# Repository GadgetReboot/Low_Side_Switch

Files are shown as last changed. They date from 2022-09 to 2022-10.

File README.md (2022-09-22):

# Low Side Switch
16 channel low-side switch for driving resistive/inductive loads<br><br>
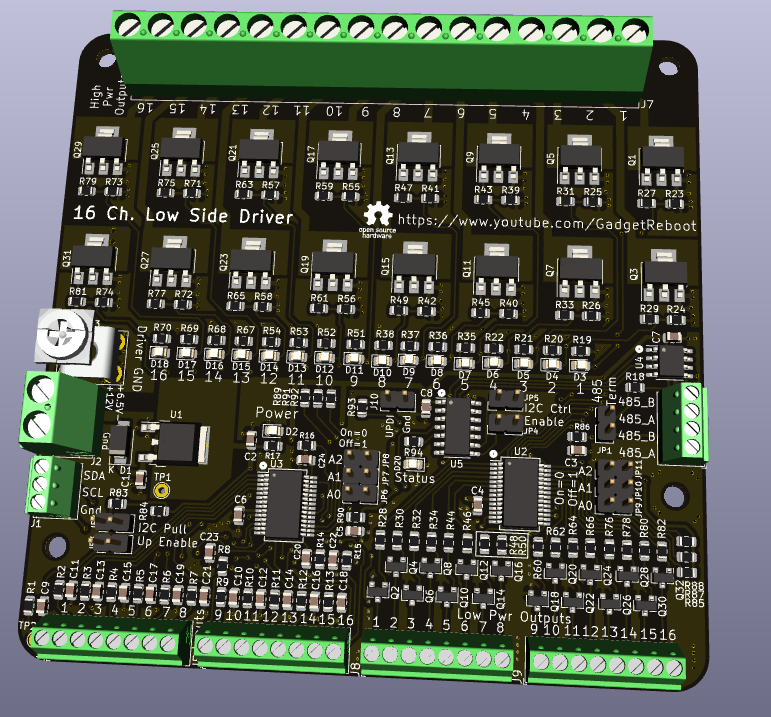
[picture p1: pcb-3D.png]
pcb
<br><br>
[PCBs are available at PCBWay.com][pcbway] <br><br>
This project is intended for use in a hobby electronics project environment, eg. a controlled research and development work shop to assist in the design and test of various other projects, ideas, and concepts.

It is not intended to be used as a stand alone or complete/refined product.

This design may be refined on an ongoing basis as needed, including design corrections or changes to fit or function.

If used in a situation where safety or other regulatory approval is required, it is the responsibility of the user of this design to ensure all applicable laws and regulations are followed.<br><br>

Shield: [][cc-by-sa]

This work is licensed under a
[Creative Commons Attribution-ShareAlike 4.0 International License][cc-by-sa].

[][cc-by-sa]

[cc-by-sa]: http://creativecommons.org/licenses/by-sa/4.0/
[cc-by-sa-image]: https://licensebuttons.net/l/by-sa/4.0/88x31.png
[cc-by-sa-shield]: https://img.shields.io/badge/License-CC%20BY--SA%204.0-lightgrey.svg
[pcbway]: https://www.pcbway.com/project/shareproject/16_Channel_Low_Side_Switch_Driver_fce9e224.html

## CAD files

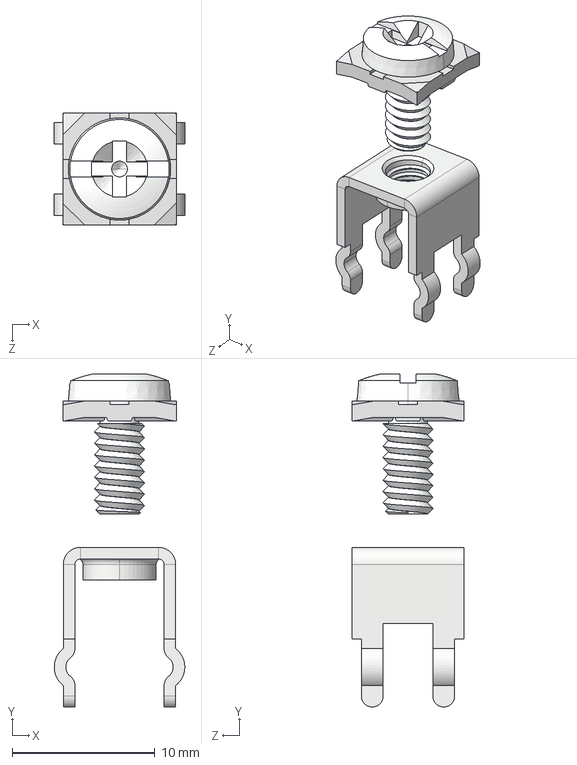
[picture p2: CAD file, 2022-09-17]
KiCad/3D_Models/keystone-PN7691-SEMS.STEP
9.14 x 23.3 x 7.87 mm

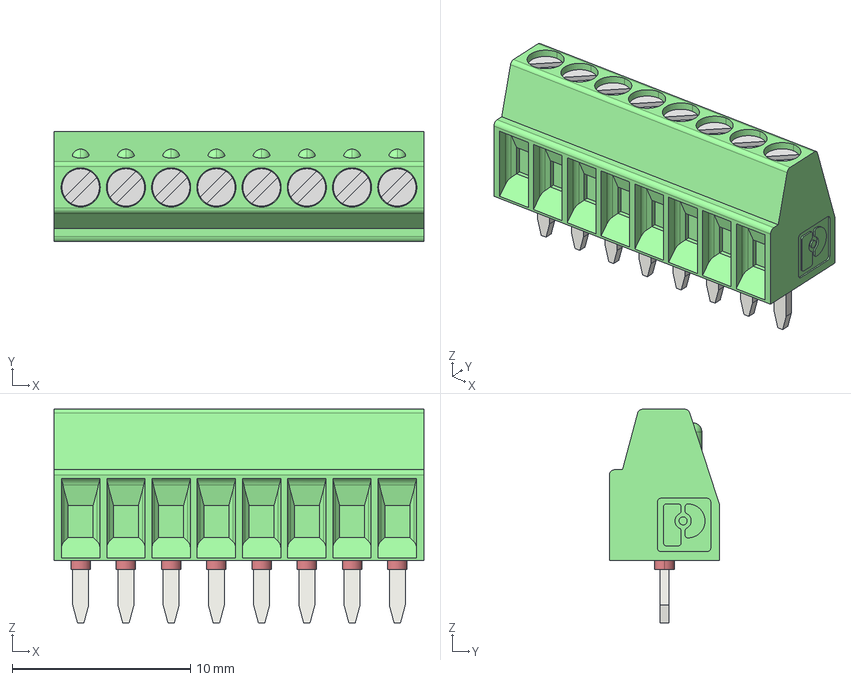
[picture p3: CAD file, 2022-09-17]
KiCad/3D_Models/1725711.stp
20.8 x 6.20 x 12.0 mm
bohrloch.2 x 8
MPT_0_5-8-2_54

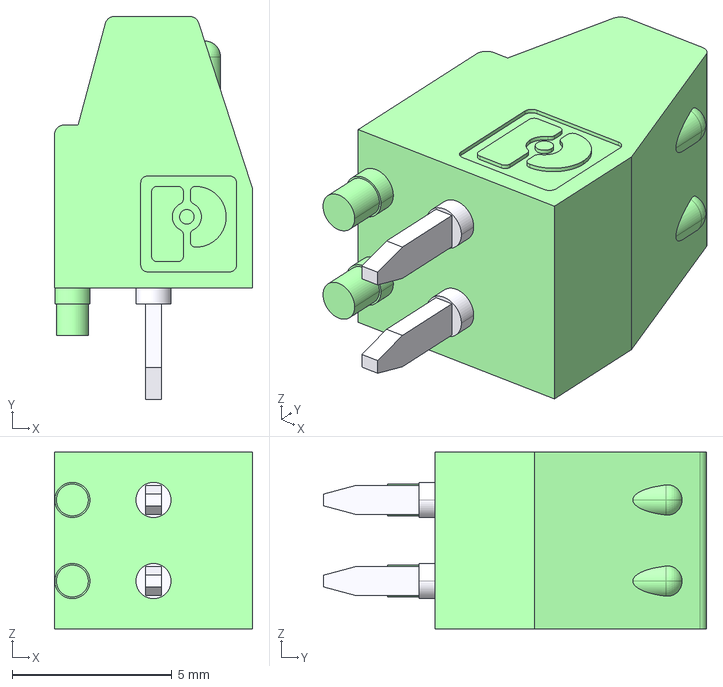
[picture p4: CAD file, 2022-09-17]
KiCad/3D_Models/1725656.stp
6.20 x 12.0 x 5.54 mm

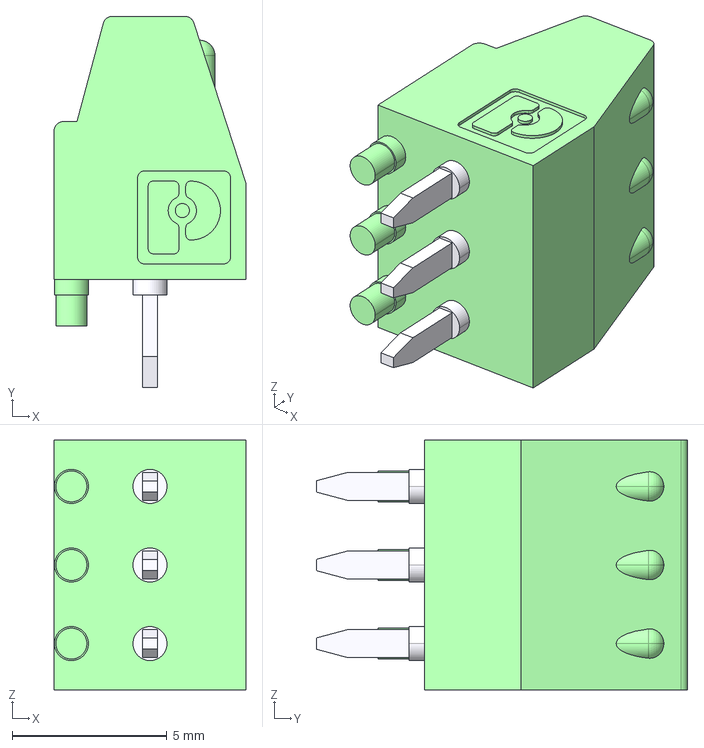
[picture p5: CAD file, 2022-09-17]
KiCad/3D_Models/1725669.stp
6.20 x 12.0 x 8.08 mm

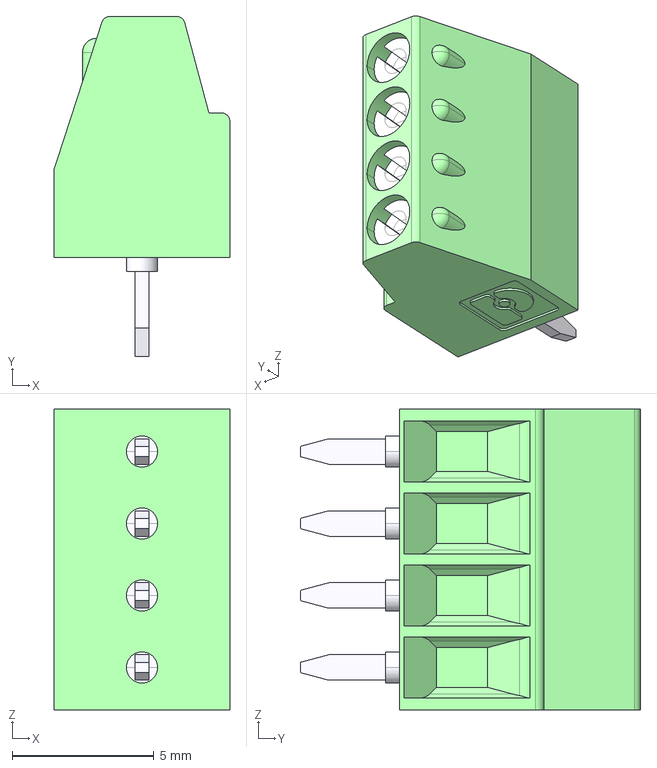
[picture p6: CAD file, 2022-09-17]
KiCad/3D_Models/1725672.stp
6.20 x 12.0 x 10.6 mm

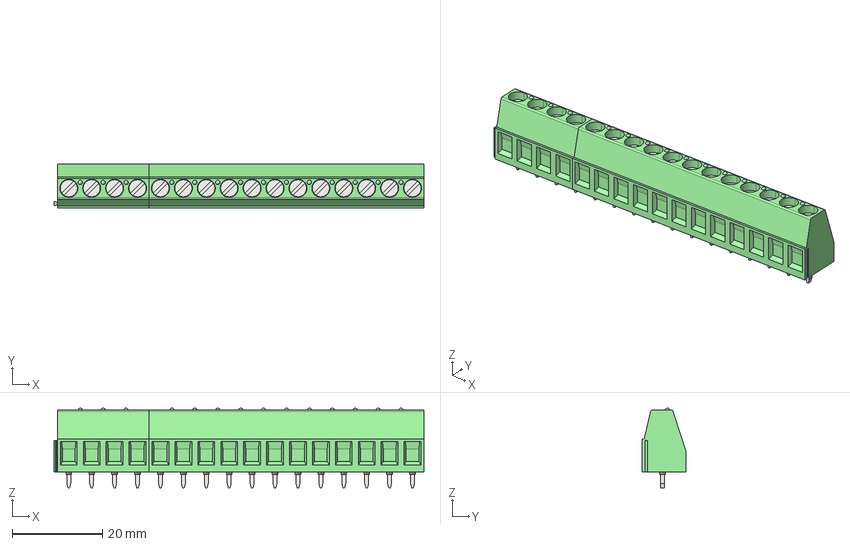
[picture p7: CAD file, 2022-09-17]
KiCad/3D_Models/1701303.stp
82.0 x 9.80 x 17.7 mm
Bohrloch_11 x 16
mkds_1.5-12-5.08
mkds_1.5-4-5.08

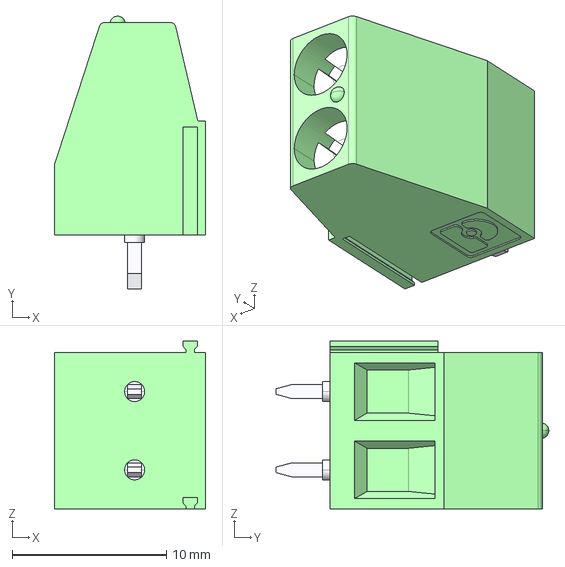
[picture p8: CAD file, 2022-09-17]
KiCad/3D_Models/1715721.stp
9.80 x 17.7 x 10.9 mm

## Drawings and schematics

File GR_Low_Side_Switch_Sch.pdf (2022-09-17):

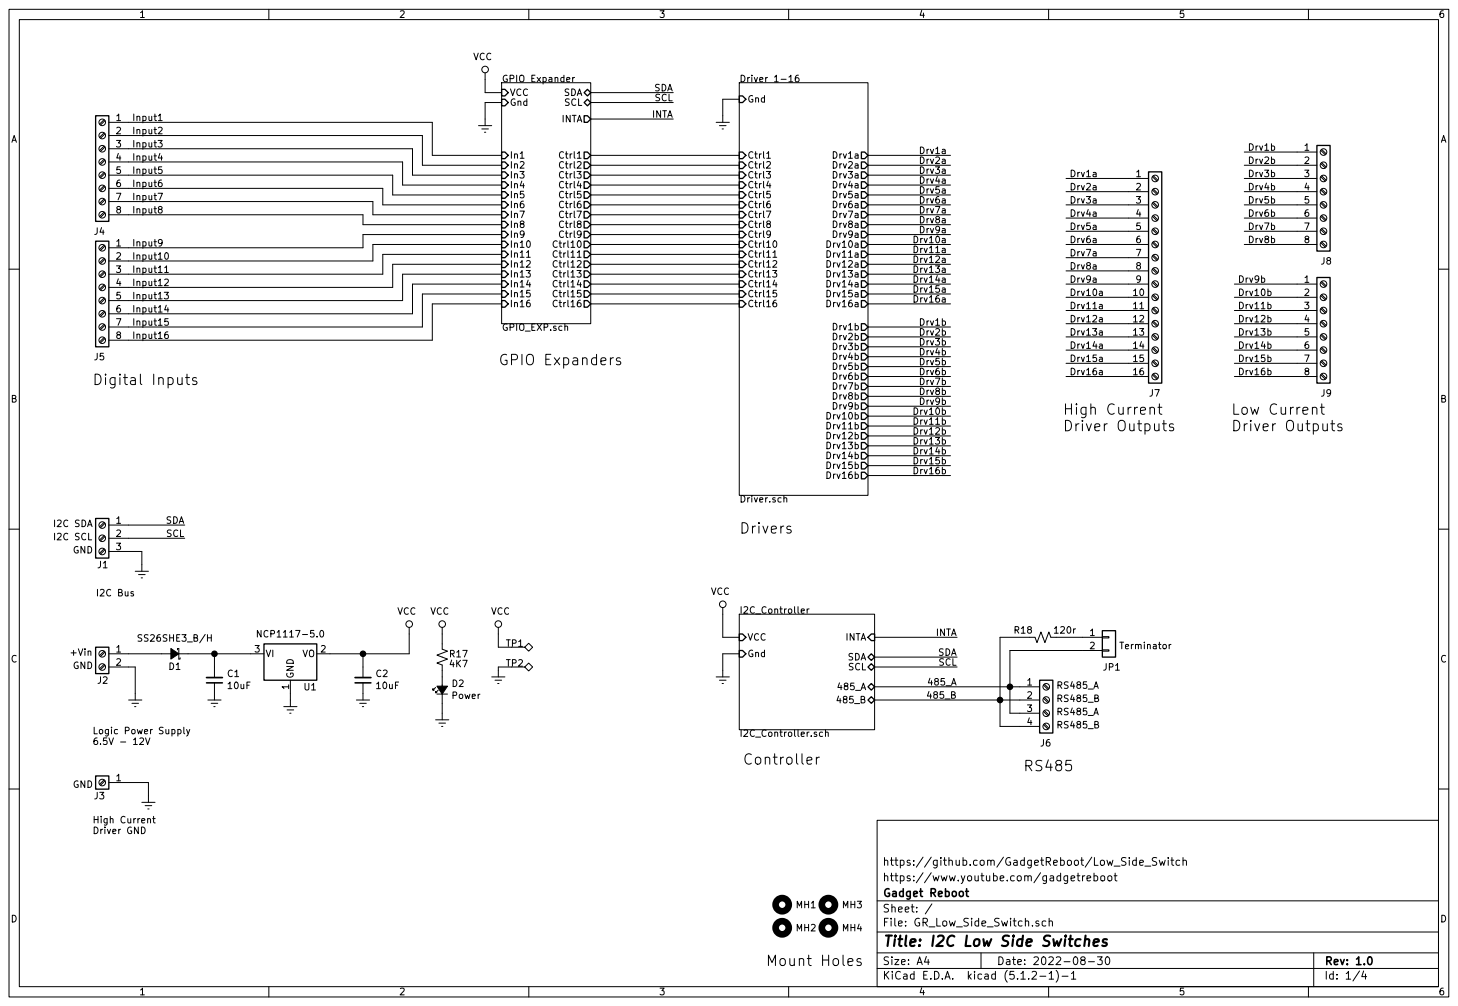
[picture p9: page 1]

High Current Driver GND

https://www.youtube.com/gadgetreboot
File: GR_Low_Side_Switch.sch Sheet: / Gadget Reboot

Id: 1/4 Title: I2C Low Side Switches

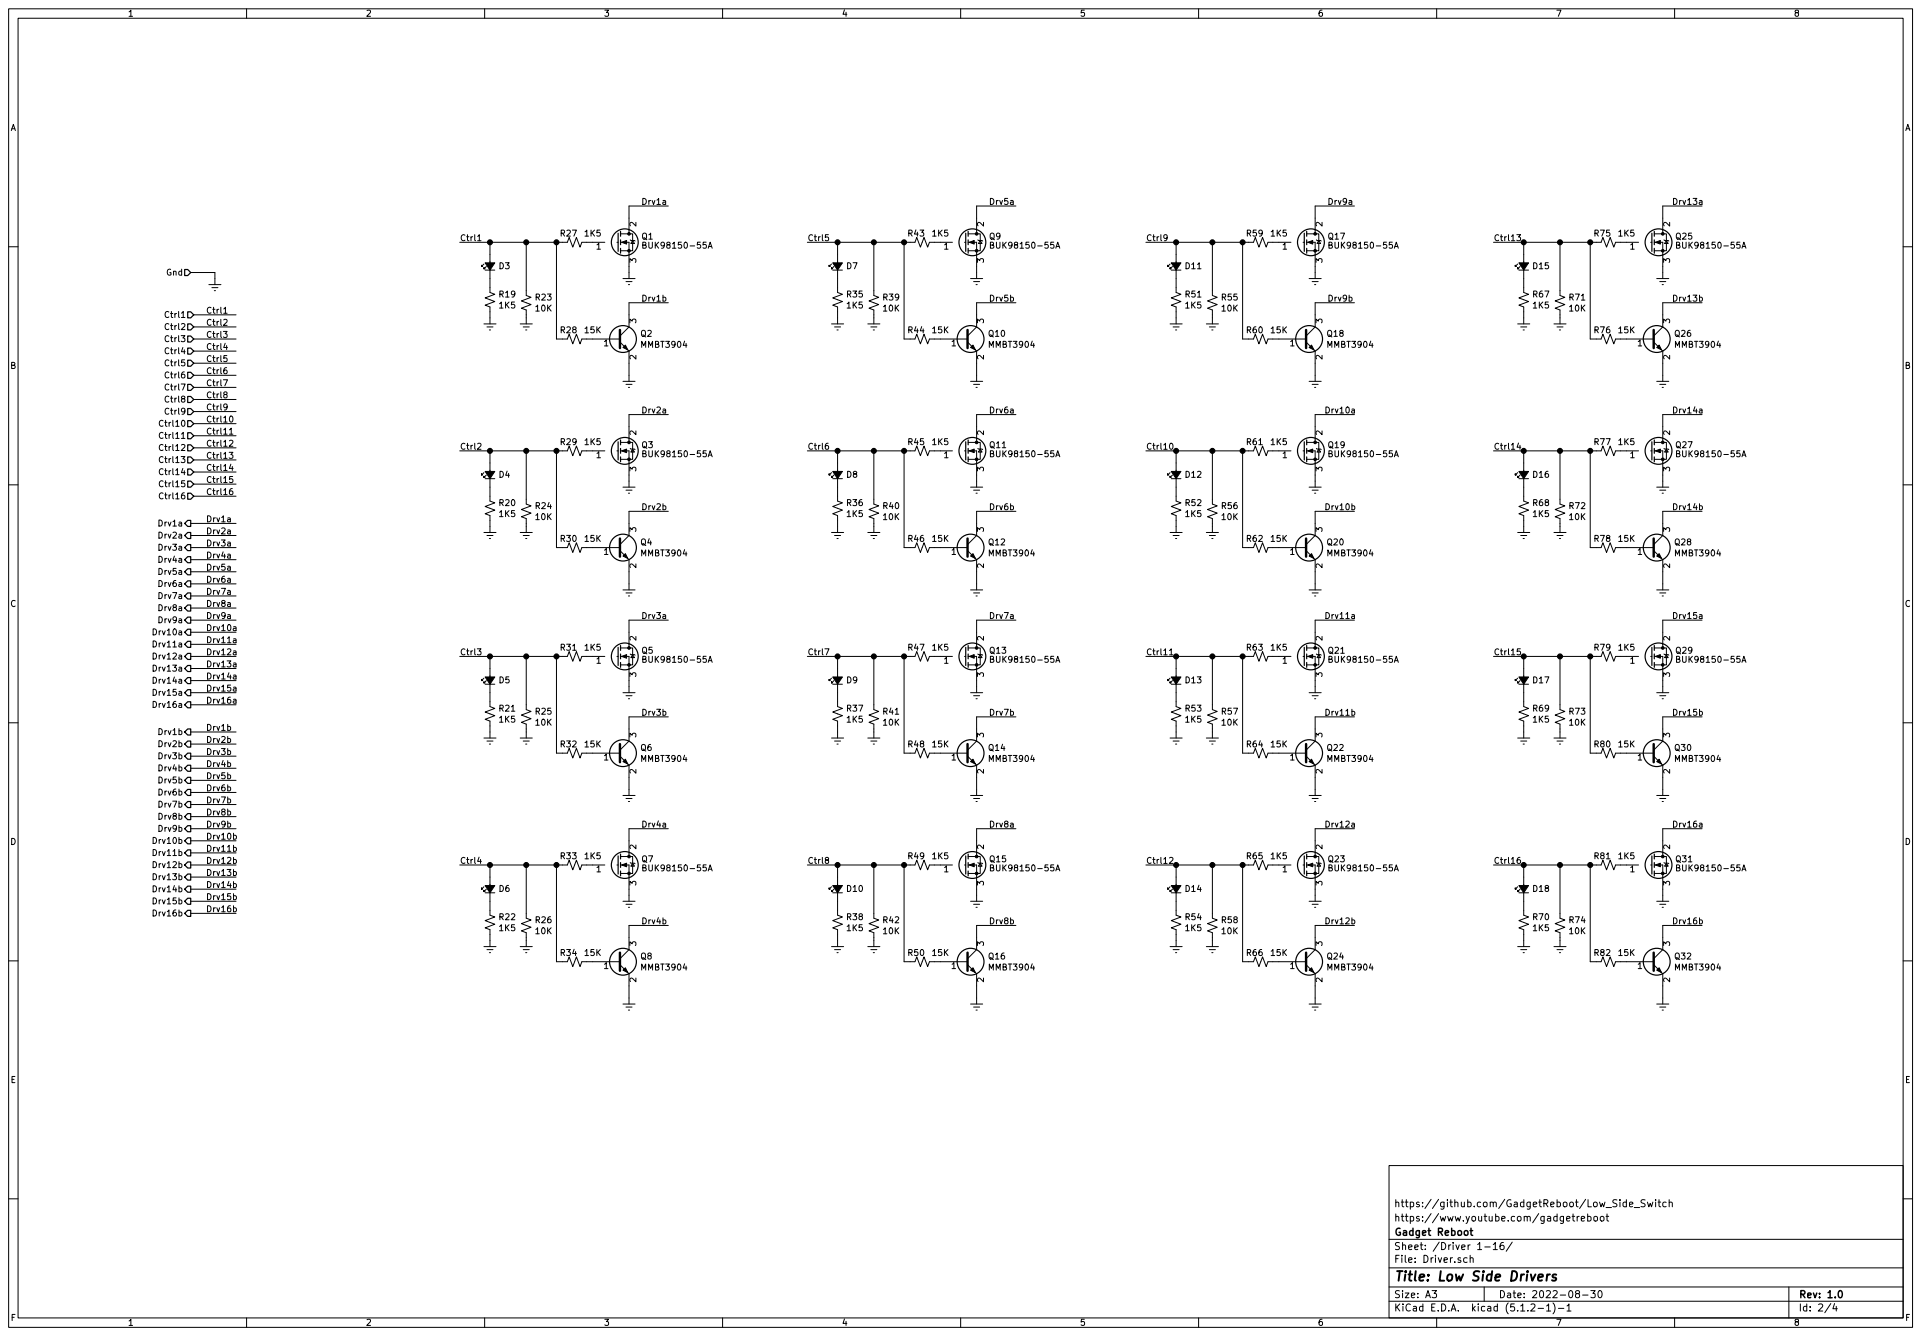
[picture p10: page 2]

https://www.youtube.com/gadgetreboot
File: Driver.sch Sheet: /Driver 1-16/ Gadget Reboot

Id: 2/4 Title: Low Side Drivers

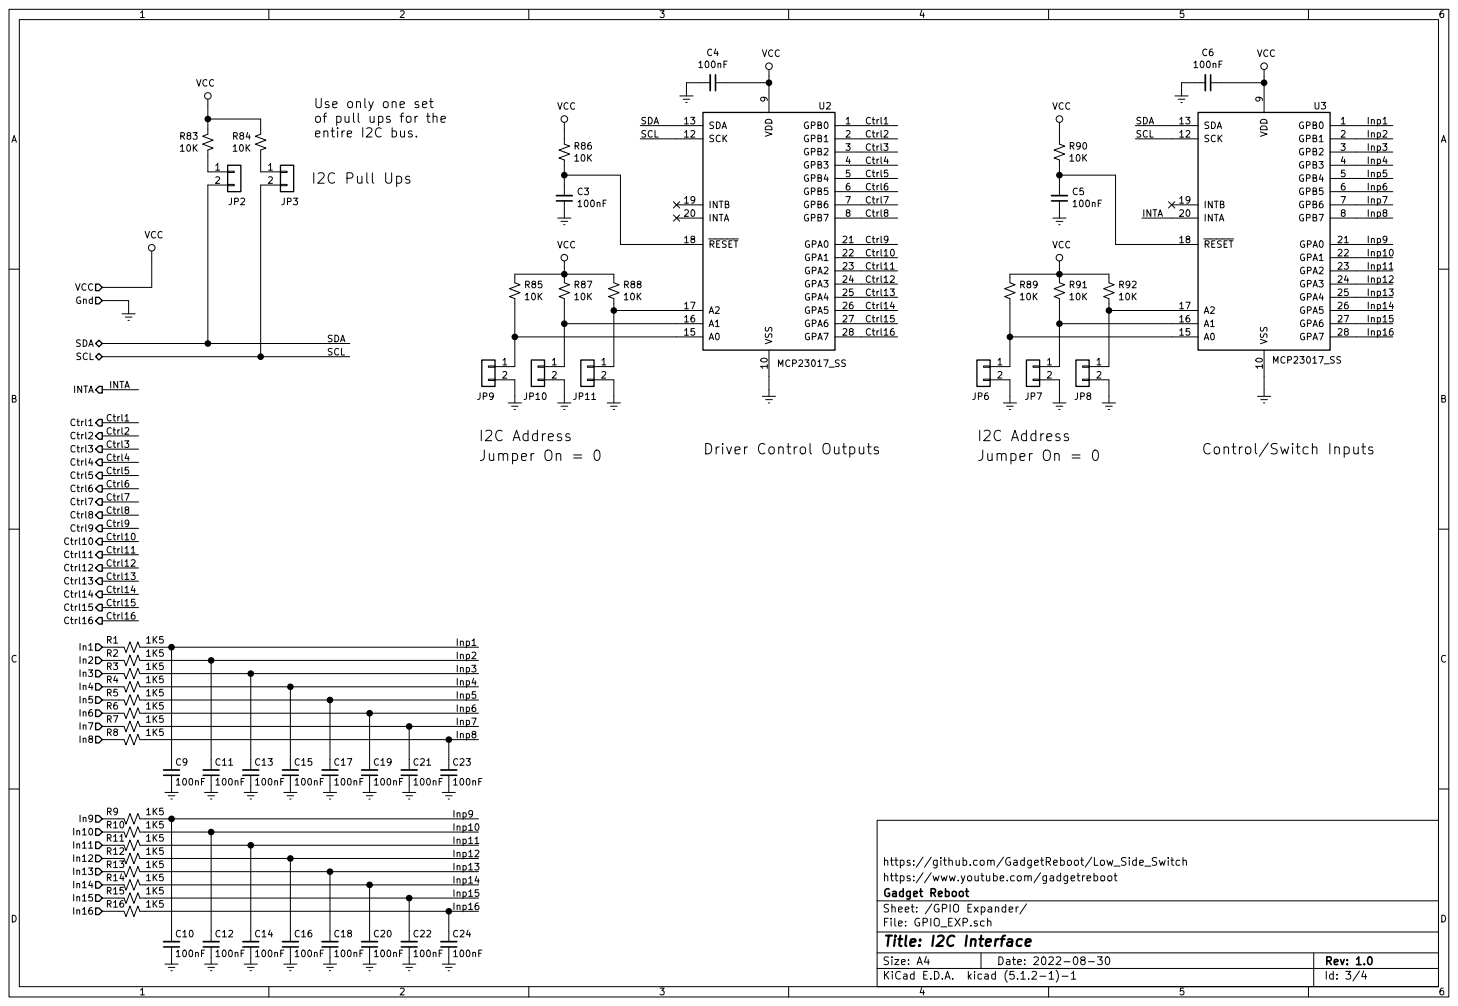
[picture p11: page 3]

Use only one set
of pull ups for the
entire I2C bus.

https://github.com/GadgetReboot/Low_Side_Switch
https://www.youtube.com/gadgetreboot
Gadget Reboot
Sheet: /GPIO Expander/
File: GPIO_EXP.sch
Id: 3/4 Title: I2C Interface

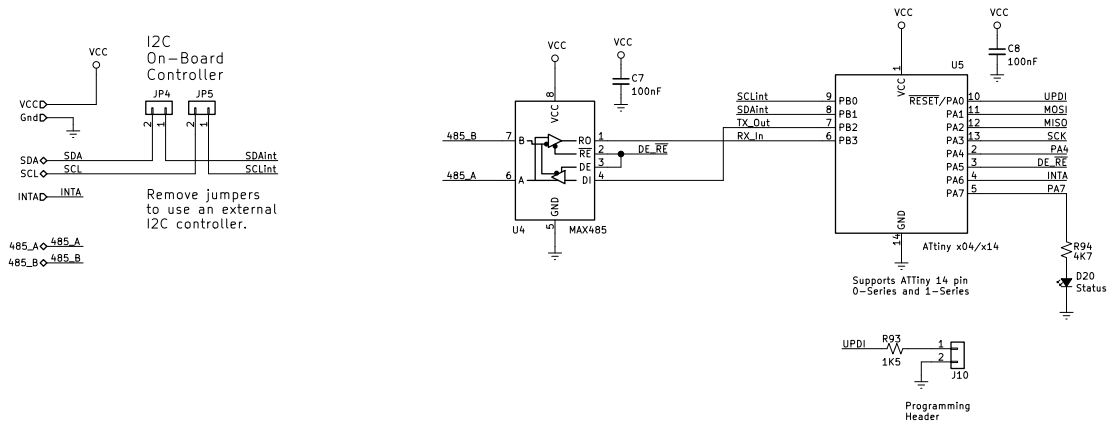
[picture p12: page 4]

Supports ATTiny 14 pin 0-Series and 1-Series VCC

Remove jumpers
to use an external

https://github.com/GadgetReboot/Low_Side_Switch
https://www.youtube.com/gadgetreboot
Gadget Reboot
Sheet: /I2C_Controller/
File: I2C_Controller.sch
Id: 4/4 Title: COMM Controller

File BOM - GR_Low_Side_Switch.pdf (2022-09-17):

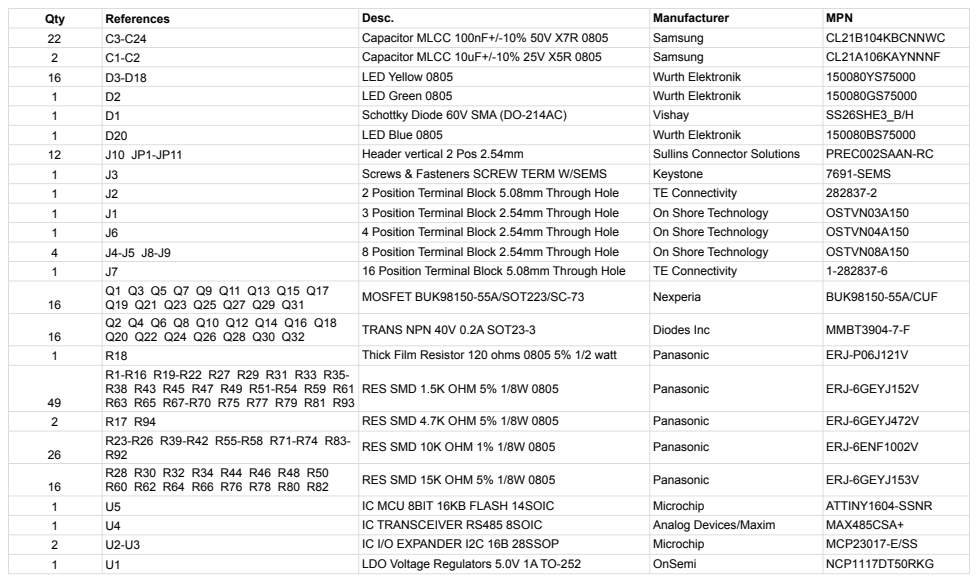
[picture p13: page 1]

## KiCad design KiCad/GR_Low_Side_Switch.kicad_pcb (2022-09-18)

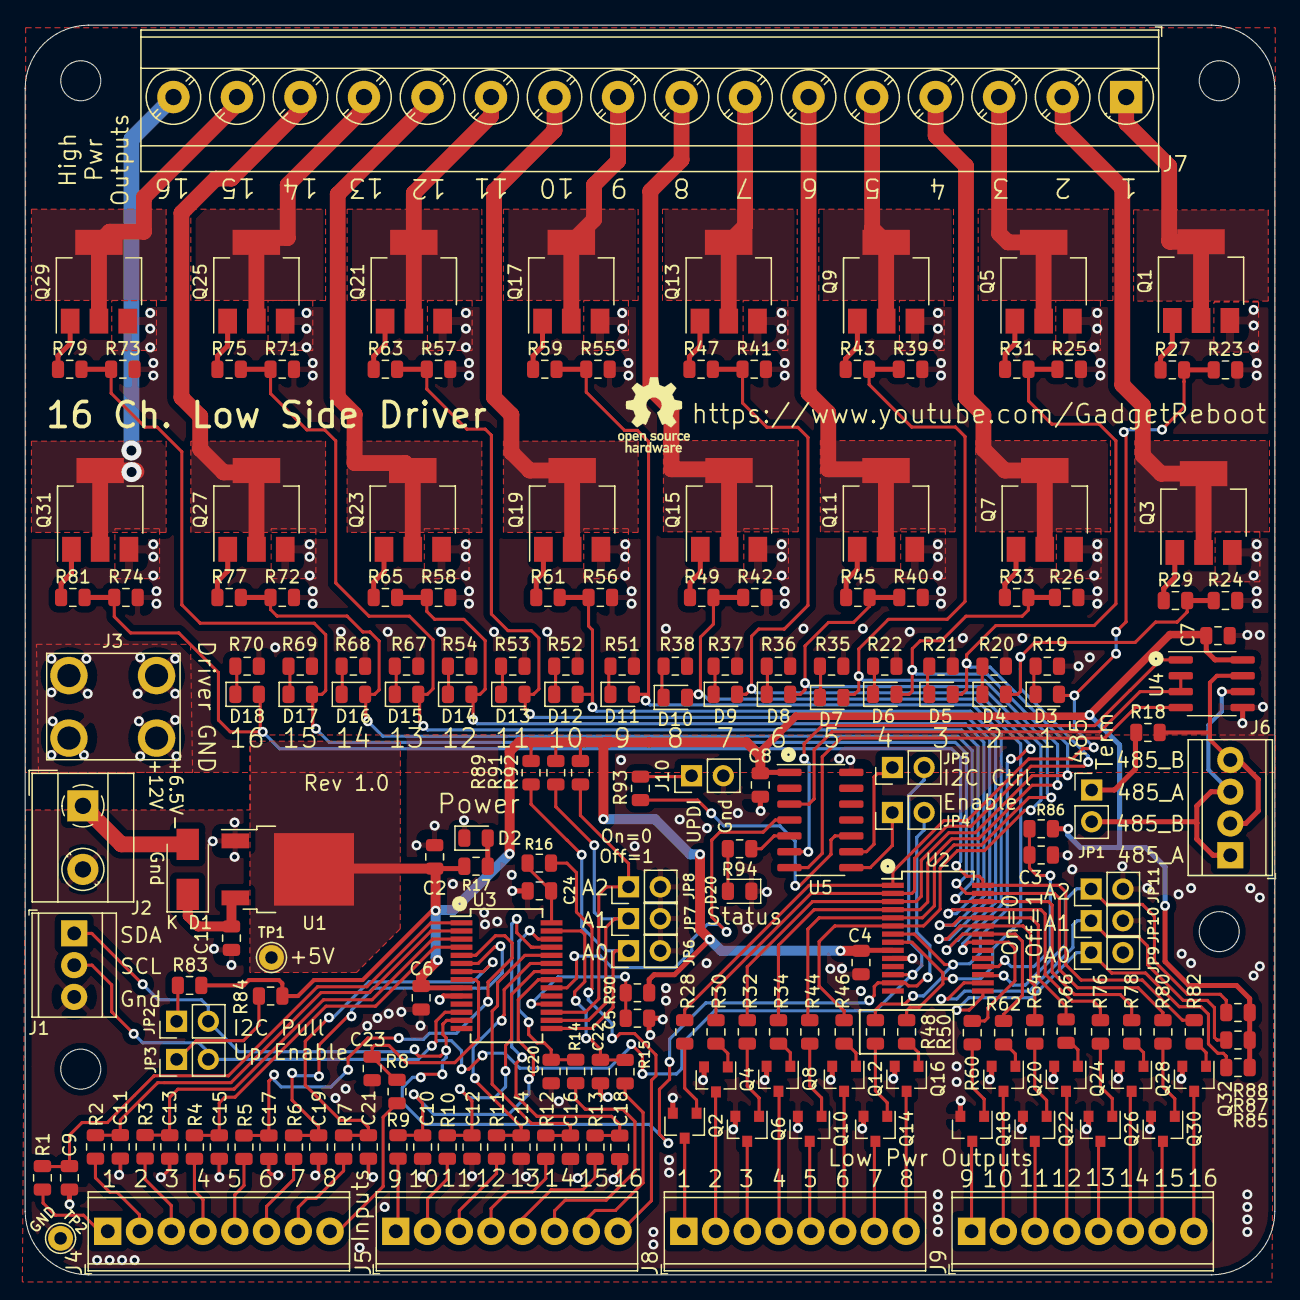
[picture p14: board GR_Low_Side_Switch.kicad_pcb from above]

Board: 2 copper layers, 99.9 x 100.0 mm, 201 parts (0 on the bottom side), 158 nets.

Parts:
C1, C2: 10uF; C_0805_2012Metric
C3, C4, C5, C6, C7, C8, C9, C10, C11, C12, C13, C14, C15, C16, C17, C18, C19, C20, C21, C22, C23, C24: 100nF; C_0805_2012Metric
D1: SS26SHE3_B/H; D_SMA
D2: Power; LED_0805_2012Metric
D3, D4, D5, D6, D7, D8, D9, D10, D11, D12, D13, D14, D15, D16, D17, D18: LED; LED_0805_2012Metric
D20: Status; LED_0805_2012Metric
J1: Screw_Terminal_01x03; TerminalBlock_TE_282834-3_1x03_P2.54mm_Horizontal
J2: Screw_Terminal_01x02; TerminalBlock_MetzConnect_Type101_RT01602HBWC_1x02_P5.08mm_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
J3: Screw_Terminal_01x01; 7691-SEMS
J4, J5, J8, J9: Screw_Terminal_01x08; TerminalBlock_Phoenix_MPT-0,5-8-2.54_1x08_P2.54mm_Horizontal
J6: Screw_Terminal_01x04; TerminalBlock_TE_282834-4_1x04_P2.54mm_Horizontal
J7: Screw_Terminal_01x16; TerminalBlock_Phoenix_MKDS-3-16-5.08_1x16_P5.08mm_Horizontal
J10: Conn_01x02; PinHeader_1x02_P2.54mm_Vertical
JP1, JP2, JP3, JP4, JP5, JP6, JP7, JP8, JP9, JP10, JP11: Conn_01x02; PinHeader_1x02_P2.54mm_Vertical
MH1, MH2, MH3, MH4: MountingHole; MountingHole_3.2mm_M3
Q1, Q3, Q5, Q7, Q9, Q11, Q13, Q15, Q17, Q19, Q21, Q23, Q25, Q27, Q29, Q31: BUK98150-55A; SOT-223-3_TabPin2
Q2, Q4, Q6, Q8, Q10, Q12, Q14, Q16, Q18, Q20, Q22, Q24, Q26, Q28, Q30, Q32: MMBT3904; SOT-23
R1, R2, R3, R4, R5, R6, R7, R8, R9, R10, R11, R12, R13, R14, R15, R16, R19, R20, R21, R22, R27, R29, R31, R33, R35, R36, R37, R38, R43, R45, R47, R49, R51, R52, R53, R54, R59, R61, R63, R65, R67, R68, R69, R70, R75, R77, R79, R81, R93: 1K5; R_0805_2012Metric
R17, R94: 4K7; R_0805_2012Metric
R18: 120r; R_0805_2012Metric
R23, R24, R25, R26, R39, R40, R41, R42, R55, R56, R57, R58, R71, R72, R73, R74, R83, R84, R85, R86, R87, R88, R89, R90, R91, R92: 10K; R_0805_2012Metric
R28, R30, R32, R34, R44, R46, R48, R50, R60, R62, R64, R66, R76, R78, R80, R82: 15K; R_0805_2012Metric
TP1, TP2: TestPoint_Alt; TestPoint_THTPad_D2.0mm_Drill1.0mm
U1: NCP1117-5.0; TO-252-2
U2, U3: MCP23017_SS; SSOP-28_5.3x10.2mm_P0.65mm_modified
U4: MAX485; SOIC-8_3.9x4.9mm_P1.27mm
U5: ATtiny x04/x14; SOIC-14_3.9x8.7mm_P1.27mm

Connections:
/485_A: J6.1, J6.3, JP1.2, U4.6
/485_B: J6.2, J6.4, R18.2, U4.7
/Driver 1-16/Ctrl1: D3.2, R23.1, R27.2, R28.2, U2.1
/Driver 1-16/Ctrl2: D4.2, R24.1, R29.2, R30.2, U2.2
/Driver 1-16/Ctrl3: D5.2, R25.1, R31.2, R32.2, U2.3
/Driver 1-16/Ctrl4: D6.2, R26.1, R33.2, R34.2, U2.4
/Driver 1-16/Ctrl5: D7.2, R39.1, R43.2, R44.2, U2.5
/Driver 1-16/Ctrl6: D8.2, R40.1, R45.2, R46.2, U2.6
/Driver 1-16/Ctrl7: D9.2, R41.1, R47.2, R48.2, U2.7
/Driver 1-16/Ctrl8: D10.2, R42.1, R49.2, R50.2, U2.8
/Driver 1-16/Ctrl9: D11.2, R55.1, R59.2, R60.2, U2.21
/Driver 1-16/Ctrl10: D12.2, R56.1, R61.2, R62.2, U2.22
/Driver 1-16/Ctrl11: D13.2, R57.1, R63.2, R64.2, U2.23
/Driver 1-16/Ctrl12: D14.2, R58.1, R65.2, R66.2, U2.24
/Driver 1-16/Ctrl13: D15.2, R71.1, R75.2, R76.2, U2.25
/Driver 1-16/Ctrl14: D16.2, R72.1, R77.2, R78.2, U2.26
/Driver 1-16/Ctrl15: D17.2, R73.1, R79.2, R80.2, U2.27
/Driver 1-16/Ctrl16: D18.2, R74.1, R81.2, R82.2, U2.28
/Drv1a: J7.1, Q1.2
/Drv1b: J8.1, Q2.3
/Drv2a: J7.2, Q3.2
/Drv2b: J8.2, Q4.3
/Drv3a: J7.3, Q5.2
/Drv3b: J8.3, Q6.3
/Drv4a: J7.4, Q7.2
/Drv4b: J8.4, Q8.3
/Drv5a: J7.5, Q9.2
/Drv5b: J8.5, Q10.3
/Drv6a: J7.6, Q11.2
/Drv6b: J8.6, Q12.3
/Drv7a: J7.7, Q13.2
/Drv7b: J8.7, Q14.3
/Drv8a: J7.8, Q15.2
/Drv8b: J8.8, Q16.3
/Drv9a: J7.9, Q17.2
/Drv9b: J9.1, Q18.3
/Drv10a: J7.10, Q19.2
/Drv10b: J9.2, Q20.3
/Drv11a: J7.11, Q21.2
/Drv11b: J9.3, Q22.3
/Drv12a: J7.12, Q23.2
/Drv12b: J9.4, Q24.3
/Drv13a: J7.13, Q25.2
/Drv13b: J9.5, Q26.3
/Drv14a: J7.14, Q27.2
/Drv14b: J9.6, Q28.3
/Drv15a: J7.15, Q29.2
/Drv15b: J9.7, Q30.3
/Drv16a: J7.16, Q31.2
/Drv16b: J9.8, Q32.3
/GPIO Expander/Inp1: C9.2, R1.1, U3.1
/GPIO Expander/Inp2: C11.2, R2.1, U3.2
/GPIO Expander/Inp3: C13.2, R3.1, U3.3
/GPIO Expander/Inp4: C15.2, R4.1, U3.4
/GPIO Expander/Inp5: C17.2, R5.1, U3.5
/GPIO Expander/Inp6: C19.2, R6.1, U3.6
/GPIO Expander/Inp7: C21.2, R7.1, U3.7
/GPIO Expander/Inp8: C23.2, R8.1, U3.8
/GPIO Expander/Inp9: C10.2, R9.1, U3.21
/GPIO Expander/Inp10: C12.2, R10.1, U3.22
/GPIO Expander/Inp11: C14.2, R11.1, U3.23
/GPIO Expander/Inp12: C16.2, R12.1, U3.24
/GPIO Expander/Inp13: C18.2, R13.1, U3.25
/GPIO Expander/Inp14: C20.2, R14.1, U3.26
/GPIO Expander/Inp15: C22.2, R15.1, U3.27
/GPIO Expander/Inp16: C24.2, R16.1, U3.28
/I2C_Controller/DE_~RE: U4.2, U4.3, U5.3
/I2C_Controller/PA7: R94.1, U5.5
/I2C_Controller/RX_In: U4.1, U5.6
/I2C_Controller/SCLint: JP5.1, U5.9
/I2C_Controller/SDAint: JP4.1, U5.8
/I2C_Controller/TX_Out: U4.4, U5.7
/I2C_Controller/UPDI: R93.2, U5.10
/INTA: U3.20, U5.4
/Input1: J4.1, R1.2
/Input2: J4.2, R2.2
/Input3: J4.3, R3.2
/Input4: J4.4, R4.2
/Input5: J4.5, R5.2
/Input6: J4.6, R6.2
/Input7: J4.7, R7.2
/Input8: J4.8, R8.2
/Input9: J5.1, R9.2
/Input10: J5.2, R10.2
/Input11: J5.3, R11.2
/Input12: J5.4, R12.2
/Input13: J5.5, R13.2
/Input14: J5.6, R14.2
/Input15: J5.7, R15.2
/Input16: J5.8, R16.2
/SCL: J1.2, JP3.2, JP5.2, U2.12, U3.12
/SDA: J1.1, JP2.2, JP4.2, U2.13, U3.13
GNDREF: C1.1, C2.1, C3.1, C4.2, C5.1, C6.2, C7.2, C8.2, C9.1, C10.1, C11.1, C12.1, C13.1, C14.1, C15.1, C16.1, C17.1, C18.1, C19.1, C20.1, C21.1, C22.1, C23.1, C24.1, D2.1, D20.1, J1.3, J2.2, J3.1, J10.2, JP6.2, JP7.2, JP8.2, JP9.2, JP10.2, JP11.2, Q1.3, Q2.2, Q3.3, Q4.2, Q5.3, Q6.2, Q7.3, Q8.2, Q9.3, Q10.2, Q11.3, Q12.2, Q13.3, Q14.2, Q15.3, Q16.2, Q17.3, Q18.2, Q19.3, Q20.2, Q21.3, Q22.2, Q23.3, Q24.2, Q25.3, Q26.2, Q27.3, Q28.2, Q29.3, Q30.2, Q31.3, Q32.2, R19.2, R20.2, R21.2, R22.2, R23.2, R24.2, R25.2, R26.2, R35.2, R36.2, R37.2, R38.2, R39.2, R40.2, R41.2, R42.2, R51.2, R52.2, R53.2, R54.2, R55.2, R56.2, R57.2, R58.2, R67.2, R68.2, R69.2, R70.2, R71.2, R72.2, R73.2, R74.2, TP2.1, U1.1, U2.10, U3.10, U4.5, U5.14
unnamed: C1.2, D1.1, U1.3
unnamed: C3.2, R86.2, U2.18
unnamed: C5.2, R90.2, U3.18
unnamed: D1.2, J2.1
unnamed: D2.2, R17.2
unnamed: D3.1, R19.1
unnamed: D4.1, R20.1
unnamed: D5.1, R21.1
unnamed: D6.1, R22.1
unnamed: D7.1, R35.1
unnamed: D8.1, R36.1
unnamed: D9.1, R37.1
unnamed: D10.1, R38.1
unnamed: D11.1, R51.1
unnamed: D12.1, R52.1
unnamed: D13.1, R53.1
unnamed: D14.1, R54.1
unnamed: D15.1, R67.1
unnamed: D16.1, R68.1
unnamed: D17.1, R69.1
unnamed: D18.1, R70.1
unnamed: D20.2, R94.2
unnamed: J10.1, R93.1
unnamed: JP1.1, R18.1
unnamed: JP2.1, R83.2
unnamed: JP3.1, R84.2
unnamed: JP6.1, R89.2, U3.15
unnamed: JP7.1, R91.2, U3.16
unnamed: JP8.1, R92.2, U3.17
unnamed: JP9.1, R85.2, U2.15
unnamed: JP10.1, R87.2, U2.16
unnamed: JP11.1, R88.2, U2.17
unnamed: Q1.1, R27.1
unnamed: Q2.1, R28.1
unnamed: Q3.1, R29.1
unnamed: Q4.1, R30.1
unnamed: Q5.1, R31.1
unnamed: Q6.1, R32.1
unnamed: Q7.1, R33.1
unnamed: Q8.1, R34.1
unnamed: Q9.1, R43.1
unnamed: Q10.1, R44.1
unnamed: Q11.1, R45.1
unnamed: Q12.1, R46.1
unnamed: Q13.1, R47.1
unnamed: Q14.1, R48.1
unnamed: Q15.1, R49.1
unnamed: Q16.1, R50.1
unnamed: Q17.1, R59.1
unnamed: Q18.1, R60.1
unnamed: Q19.1, R61.1
unnamed: Q20.1, R62.1
unnamed: Q21.1, R63.1
unnamed: Q22.1, R64.1
unnamed: Q23.1, R65.1
unnamed: Q24.1, R66.1
unnamed: Q25.1, R75.1
unnamed: Q26.1, R76.1
unnamed: Q27.1, R77.1
unnamed: Q28.1, R78.1
unnamed: Q29.1, R79.1
unnamed: Q30.1, R80.1
unnamed: Q31.1, R81.1
unnamed: Q32.1, R82.1
VCC: C2.2, C4.1, C6.1, C7.1, C8.1, R17.1, R83.1, R84.1, R85.1, R86.1, R87.1, R88.1, R89.1, R90.1, R91.1, R92.1, TP1.1, U1.2, U2.9, U3.9, U4.8, U5.1

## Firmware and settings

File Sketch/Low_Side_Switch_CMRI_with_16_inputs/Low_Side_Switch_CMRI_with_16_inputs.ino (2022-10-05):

// Low Side Driver pcb
// CMRI prototype sketch for RS485 control of the outputs
// Creates 16 outputs and 32 inputs
//   (16 solenoids with 16 feedback signals (byte 0,1) plus 16 inputs from screw terminals (byte 2, 3))
//
// PCB project/target hardware:  https://github.com/GadgetReboot/Low_Side_Switch
// Notes: -PCB may need to be powered off/on after uploading a sketch
//        -PCB must be powered by main power connector for programming.  The
//         pcb isn't set up to be powered by the UPDI programmer.
//
// Libraries used:  Auto485 https://github.com/madleech/Auto485
//                  ArduinoCMRI https://github.com/madleech/ArduinoCMRI
//                  Adafruit MCP23017 https://github.com/adafruit/Adafruit-MCP23017-Arduino-Library
//                  ATTiny board file support: https://github.com/SpenceKonde/megaTinyCore
//
// Target device:    ATTiny1604 (using megaTinyCore board support), MCP23017 (I2C version)
//                   Can substitute other 1604 compatible devices depending on program space
//                   requirements eg. 804, 1614 etc
//
// Refer to ATTiny1604 Arduino pinouts:
// https://github.com/SpenceKonde/megaTinyCore/blob/master/megaavr/extras/ATtiny_x04.md
//
// Arduino pin number map for MCP23017 physical GPIO pins
// Note:  the low side driver pcb signal names map as follows:
//        Inputs or Outputs 1..8  map to GPB0..GPB7
//        Inputs or Outputs 9..16  map to GPA0..GPA7
//
// mcp23017 pin #  pin name      Arduino sketch pin #
//     21            GPA0             0
//     22            GPA1             1
//     23            GPA2             2
//     24            GPA3             3
//     25            GPA4             4
//     26            GPA5             5
//     27            GPA6             6
//     28            GPA7             7
//      1            GPB0             8
//      2            GPB1             9
//      3            GPB2             10
//      4            GPB3             11
//      5            GPB4             12
//      6            GPB5             13
//      7            GPB6             14
//      8            GPB7             15
//
// Tested with Arduino IDE 1.8.13
// Gadget Reboot
// https://www.youtube.com/gadgetreboot


#include <Adafruit_MCP23X17.h>

// create mcp23017 objects to interact with
Adafruit_MCP23X17 gpioInputs;   // mcp23017 connected as inputs
Adafruit_MCP23X17 gpioOutputs;  // mcp23017 connected as outputs

// set I2C addresses for mcp23017 inputs and outputs
// based on pcb jumper settings
#define inputsAddr  0x20     // mcp23017 address for inputs
#define outputsAddr 0x21     // mcp23017 address for outputs

// map pcb inputs and outputs to MCP23017 Arduino mapped pin numbers
// the banks of 8 gpio are not assigned one to one with
// the pcb's 1 thru 16 numbering.
// eg. pcb inputs 1 thru 8 correspond to Arduino
// gpio 8 thru 15 to simplify pcb wiring

// pcb inputs are connected to mcp23017 at address "inputsAddr"

#define input1    8   // GPB0 input
#define input2    9   // GPB1 input
#define input3    10  // GPB2 input
#define input4    11  // GPB3 input
#define input5    12  // GPB4 input
#define input6    13  // GPB5 input
#define input7    14  // GPB6 input
#define input8    15  // GPB7 input

#define input9     0   // GPA0 input
#define input10    1   // GPA1 input
#define input11    2   // GPA2 input
#define input12    3   // GPA3 input
#define input13    4   // GPA4 input
#define input14    5   // GPA5 input
#define input15    6   // GPA6 input
#define input16    7   // GPA7 input

// pcb outputs are connected to mcp23017 at address "outputsAddr"

#define output1     8   // GPB0 output
#define output2     9   // GPB1 output
#define output3     10  // GPB2 output
#define output4     11  // GPB3 output
#define output5     12  // GPB4 output
#define output6     13  // GPB5 output
#define output7     14  // GPB6 output
#define output8     15  // GPB7 output

#define output9     0   // GPA0 output
#define output10    1   // GPA1 output
#define output11    2   // GPA2 output
#define output12    3   // GPA3 output
#define output13    4   // GPA4 output
#define output14    5   // GPA5 output
#define output15    6   // GPA6 output
#define output16    7   // GPA7 output

#define statusLED 3                    // pcb "status" LED is on ATTiny PA7 (pin 3 on Arduino)

// rs485 serial interface
#include <Auto485.h>

// rs485 driver/receiver enable pin
#define DE_PIN 1    // ATTiny PA5 = Arduino pin 1
#define RE_PIN 1

// rs485 interface using DE_PIN & RE_PIN to toggle tx/rx mode on the MAX485
Auto485 bus(DE_PIN, RE_PIN);

#include <CMRI.h>
#define CMRI_ADDR 1                       // select the CMRI node address

CMRI cmri(CMRI_ADDR, 32, 16, bus);        // 32 inputs, 16 outputs


void setup() {
  bus.begin(9600, SERIAL_8N2);          // open the RS485 bus at 9600bps

  // init mcp23017 input/output interfaces
  gpioInputs.begin_I2C(inputsAddr);
  gpioOutputs.begin_I2C(outputsAddr);

  // configure and test blink the status LED
  pinMode(statusLED, OUTPUT);
  digitalWrite(statusLED, 1);
  delay(200);
  digitalWrite(statusLED, 0);

  // configure input pins as inputs with pull up
  gpioInputs.pinMode(input1, INPUT_PULLUP);
  gpioInputs.pinMode(input2, INPUT_PULLUP);
  gpioInputs.pinMode(input3, INPUT_PULLUP);
  gpioInputs.pinMode(input4, INPUT_PULLUP);
  gpioInputs.pinMode(input5, INPUT_PULLUP);
  gpioInputs.pinMode(input6, INPUT_PULLUP);
  gpioInputs.pinMode(input7, INPUT_PULLUP);
  gpioInputs.pinMode(input8, INPUT_PULLUP);
  gpioInputs.pinMode(input9, INPUT_PULLUP);
  gpioInputs.pinMode(input10, INPUT_PULLUP);
  gpioInputs.pinMode(input11, INPUT_PULLUP);
  gpioInputs.pinMode(input12, INPUT_PULLUP);
  gpioInputs.pinMode(input13, INPUT_PULLUP);
  gpioInputs.pinMode(input14, INPUT_PULLUP);
  gpioInputs.pinMode(input15, INPUT_PULLUP);
  gpioInputs.pinMode(input16, INPUT_PULLUP);

  // configure output pins as outputs
  gpioOutputs.pinMode(output1, OUTPUT);
  gpioOutputs.pinMode(output2, OUTPUT);
  gpioOutputs.pinMode(output3, OUTPUT);
  gpioOutputs.pinMode(output4, OUTPUT);
  gpioOutputs.pinMode(output5, OUTPUT);
  gpioOutputs.pinMode(output6, OUTPUT);
  gpioOutputs.pinMode(output7, OUTPUT);
  gpioOutputs.pinMode(output8, OUTPUT);
  gpioOutputs.pinMode(output9, OUTPUT);
  gpioOutputs.pinMode(output10, OUTPUT);
  gpioOutputs.pinMode(output11, OUTPUT);
  gpioOutputs.pinMode(output12, OUTPUT);
  gpioOutputs.pinMode(output13, OUTPUT);
  gpioOutputs.pinMode(output14, OUTPUT);
  gpioOutputs.pinMode(output15, OUTPUT);
  gpioOutputs.pinMode(output16, OUTPUT);

  // set outputs low/off
  gpioOutputs.writeGPIO(0x00, 0);  // port A (outputs 9..16) write 0x00
  gpioOutputs.writeGPIO(0x00, 1);  // port B (outputs 1..8)  write 0x00


}

void loop() {
  // 1: main processing node of cmri library
  cmri.process();

  // 2: update output
  for (int i = 0; i <= 7; i++) {
    gpioOutputs.digitalWrite(i + 8, cmri.get_bit(i));      // send corresponding cmri bits to pcb outputs 1..8 (gpio 8..15 in Arduino)
  }
  for (int i = 8; i <= 15; i++) {
    gpioOutputs.digitalWrite(i - 8, cmri.get_bit(i));      // send corresponding cmri bits to pcb outputs 9..16 (gpio 0..7 in Arduino)
  }

  // 3: update inputs
  cmri.set_byte(0, gpioOutputs.readGPIO(1) );              // read the 1st byte from "output" mcp23017 port B (outputs 1..8)
  cmri.set_byte(1, gpioOutputs.readGPIO(0) );              // read the 2nd byte from "output" mcp23017 port A (outputs 9..16)
  cmri.set_byte(2, (byte)~gpioInputs.readGPIO(1) );       // read the 3rd byte from "input"  mcp23017 port B (inputs 1..8) and invert
  cmri.set_byte(3, (byte)~gpioInputs.readGPIO(0) );       // read the 4th byte from "input"  mcp23017 port A (inputs 9..16) and invert

}

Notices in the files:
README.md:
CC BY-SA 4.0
